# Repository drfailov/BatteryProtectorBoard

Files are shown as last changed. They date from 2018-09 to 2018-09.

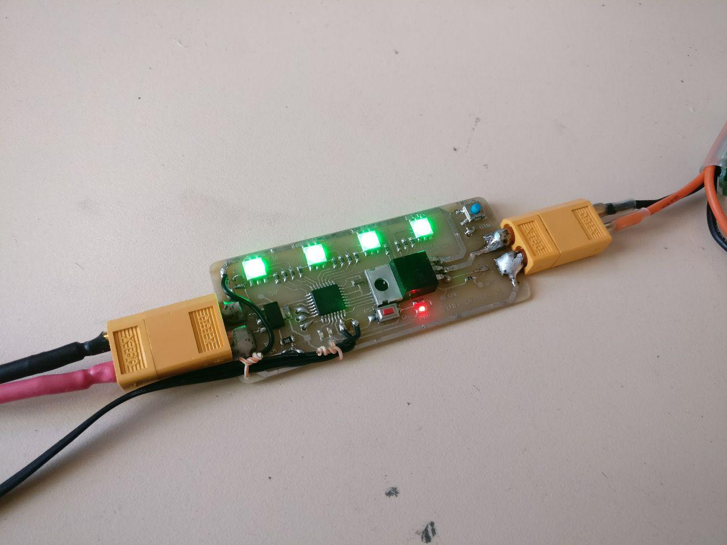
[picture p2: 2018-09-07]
Doc/2018-06-06 Board prototype.jpg

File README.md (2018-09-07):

# BatteryProtectorBoard
Этот проект описывает плату защиты акуумулятора и включает в себя: 
- Схему устройства
- Чертёж платы 
- Исходник платы в виде EasyEDA JSON
- Прошивку для Atmel 328p
- Схемы, чертежи, наброски
- Фото прототипа платы

Характеристики: 
- Рабочее напряжение: 5-15В
- Потребление тока в простое: 35мА
- Потребление тока минимум 20мА максимум 70 мА
- Рабочий ток для подключённого устройства: 1А
- Пиковый ток для подключённого устройства: 3А
- Точность измерения напряжения +-0.05В

Плата состоит из:
- Тестолитовая плата, 2 сторонняя
- Atmel 328p
- Диод 1n4007
- Кварцевый резонатор для Atmel
- Линейный стабилизатор напряжения AMS1117
- Силовой мосфет IRF520N
- 2 кнопки
- 4 RGB светодиода
- 2 разъёма XT-60
- 3 SMD светодиода
- 2 конденсатора 100мкФ 25В (для стабилизации напряжения)
- 1 SMD резистор на 180 Ом (маркировка 181) (для делителя напряжения)
- 1 SMD резистор на 2.2 кОм (маркировка 222) (для делителя напряжения)
- 15 SMD резисторов на 1 кОм (маркировка 102 или 1001)

Умеет делать:
- Измерять напряжение на входе
- Управлять питанием устройства на выхоже
- Отключать устройство при достижении нижнего порога напряжения
- Отключать устройство при достижении верхнего порога напряжения
- Отключать устройство с кнопки (если подержать секунду)
- Показывать уровень заряда 4мя светодиодами (с учётом нелинейности падения напряжения для литиевых аккумуляторов)
- Калиброваться в диапазоне напряжений 5В - 18В (по дефолту калиброван для 3S аккумулятора)
- Программироваться как Arduino, можно допиливать по своему усмотрению

Как изготавливать:
- Изготовить плату последней версии в папке с Gerber файлами.
- Распаять комплектуху. Atmel идеально снимать с Arduino Pro Mini, она уже прошита так как нужно.
- Открыть скетч в редакторе Arduino, скомпилировать.
- Прошить плату по UART через FTDI программатор. Во время прошивки ткнуть reset, чтобы началась прошивка.
- Проверить расниновку светодиодов на плате и соответствие цветов. Заряд более 40% должен отобраться зелёным, а калибровка синим.
(Если цвета не соответствуют, исправить константы описывающие распиновку диодов)
- Готово.

Как пользоваться:
После включения в течении секунды отображается анимация включения, после чего переход в режим отображеня заряда. 
В режиме отображения заряда заряд ниже 40% отображается розовым цветом, а заряд выше 40% отображается зелёным цветом.
При напряжении ниже минимального (стандартно это 10В) все светодиоды мигают розовым цветом, а подключённое устройство обесточивается.
При напряжении выше максимального (стандартно это 12.5В) все светодиоды мигают зелёным цветом, а подключённое устройство обесточивается.
Чтобы вручную отключить подключённое устройство, необходимо подержать кнопку 1 секунду, до завершения анимации, после чего 4й светодиод загорится синим. 
Это означает, что устройство обесточено вручную.В таком режиме плата будет находиться пока устройство не будет включено обратно вручную.  
Чтобы включить устройство обратно, требуется подержать кнопку нажатой секунду до завершения анимации, после чего плата переходит в режим отображения уровня заряда.

Как калибровать:
Диапазон напряжений можно калибровать. Он может находиться в диапазоне от 5В до 18В. 
Чтобы перейти в режим калибровки, нужно подключить плату к регулируемому блоку питания и перезагрузить плату держа нажатой кнопку выключения.
Когда режим калибровки активен, все светодиоды светят синим цветом. 
После того как Вы отпустите кнопку выключения, начнёт мигать зелёным 4й светодиод, это означает что сейчас калибруется верхний порог напряжения. 
Выставьте на блоке питания желаемое верхнее напряжение, убедитесь напряжение стабильно и нажмите кнопку включения на плате. 
В течении нескольких секунд плата будет измерять напряжение и сохранит измеренное напряжение в памяти и перейдёт в режим калибровки нижнего порога напряжения.
В режиме калибровки нижнего порога напряжения начнёт мигать 1й светодиод красным цветом. Выставьте на блоке питания желаемое нижнее напряжение и нажмите кнопку выключения. 
В течении нескольких секунд плата будет измерять напряжение и сохранит измеренное напряжение в памяти и перейдёт в режим отображения уровня заряда (нормальной работы).

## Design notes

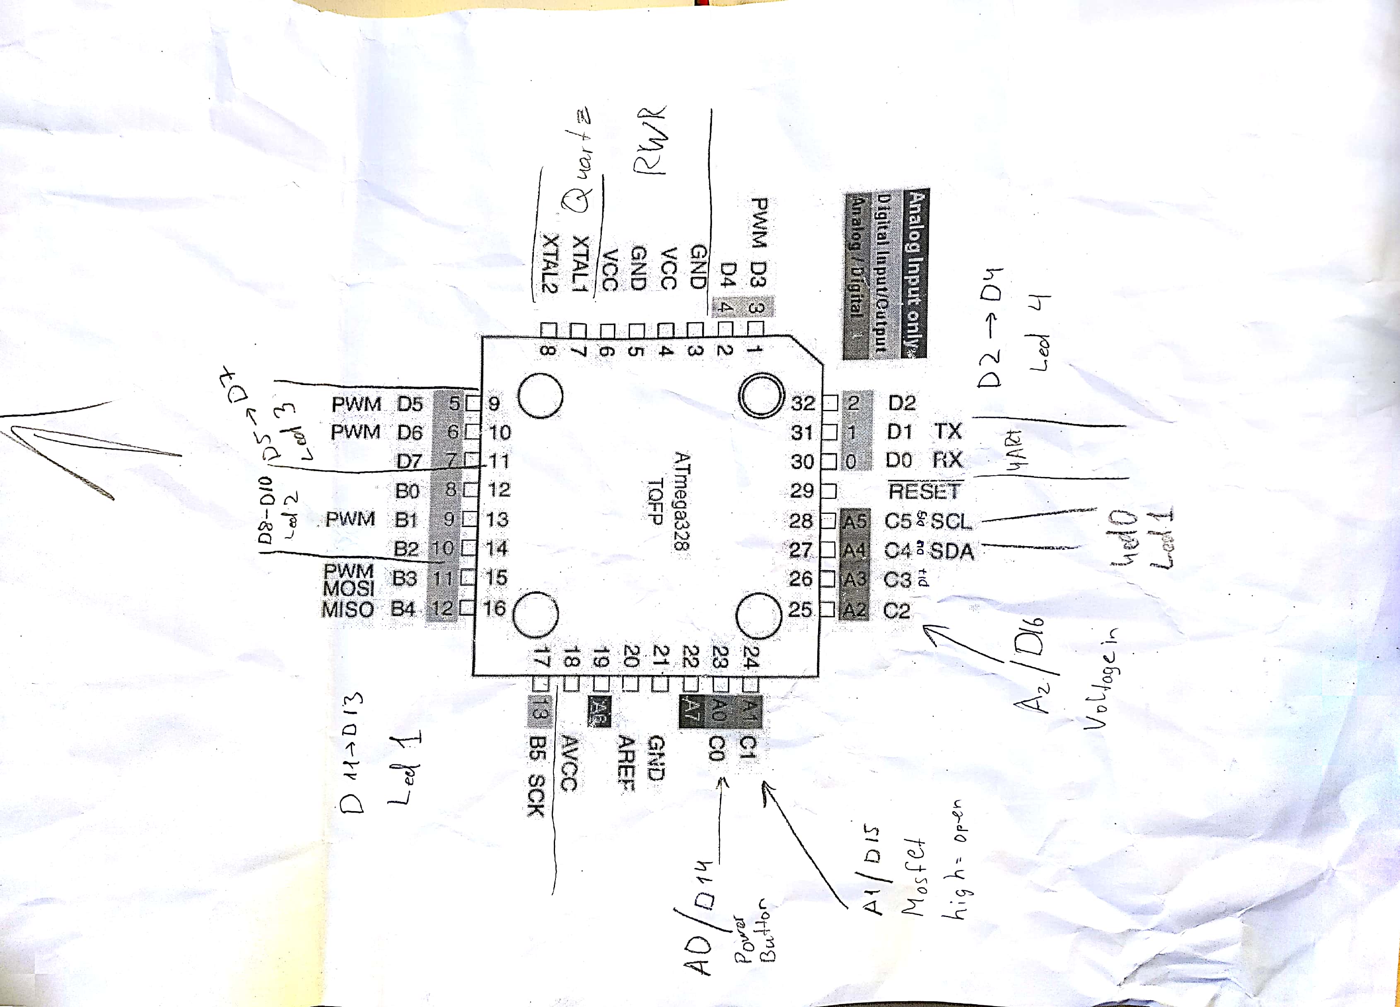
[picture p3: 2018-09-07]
Doc/2018-05-28 Atmel pinout.jpg

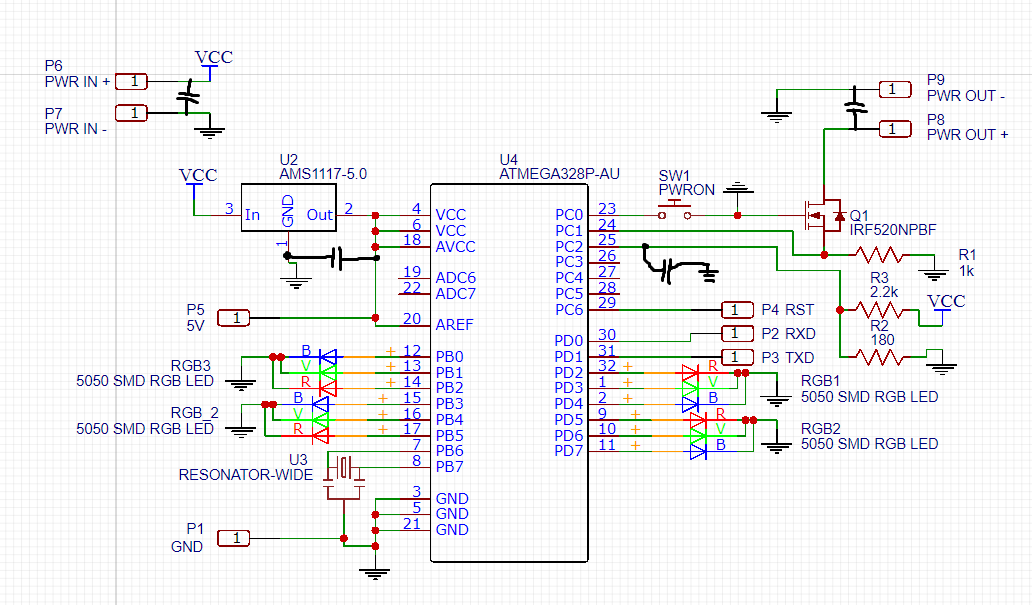
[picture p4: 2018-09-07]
Doc/2018-05-22 schematic.PNG

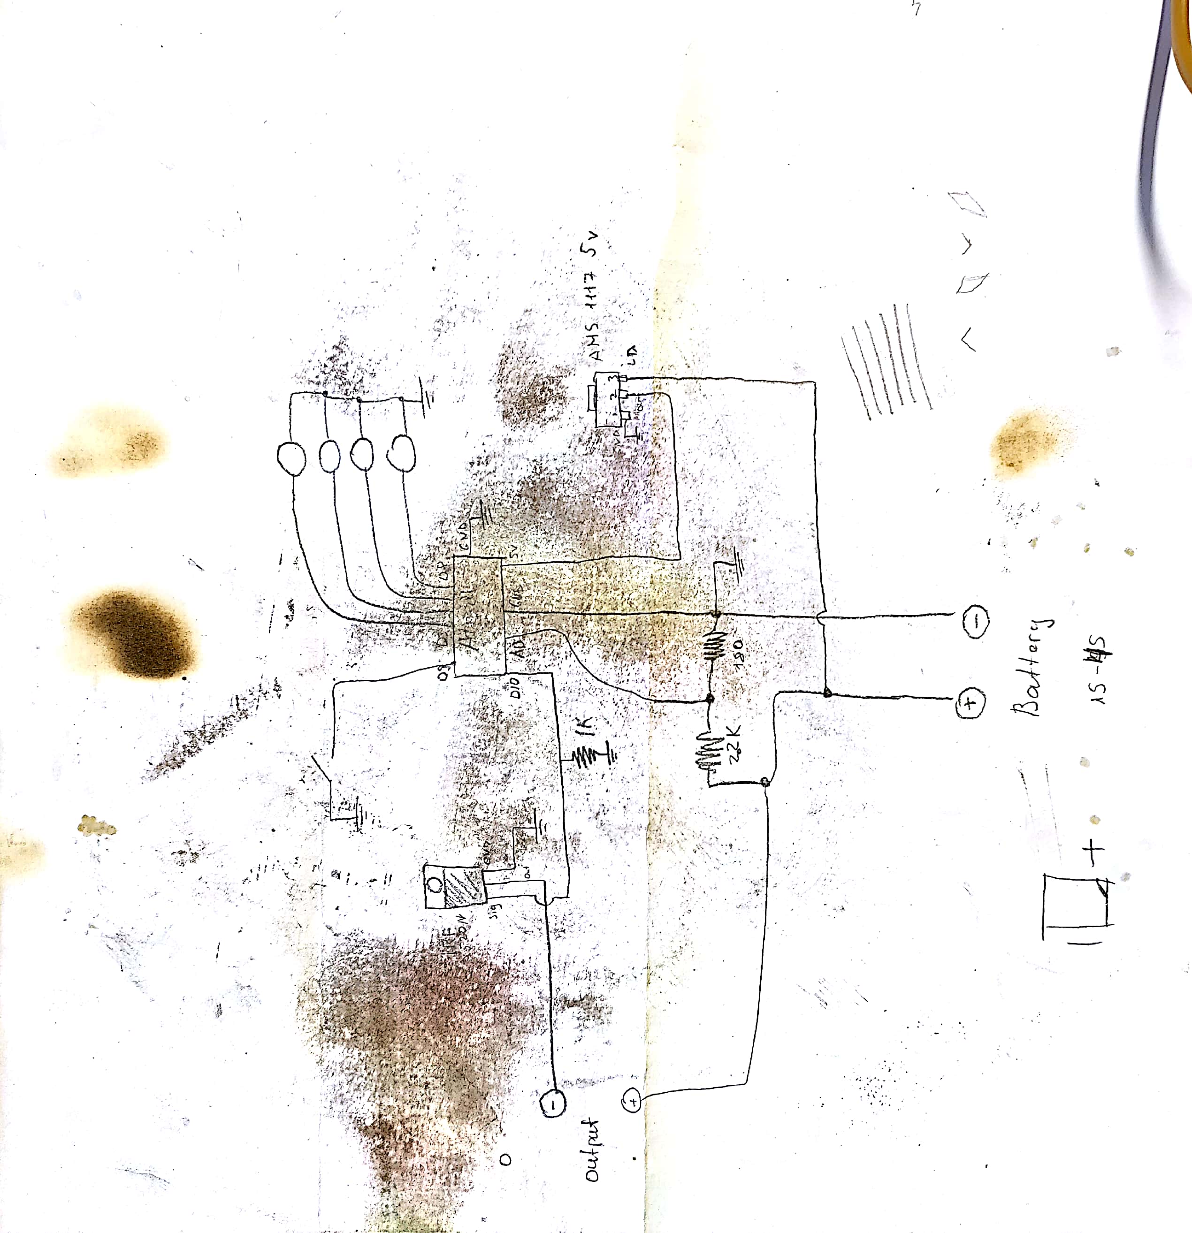
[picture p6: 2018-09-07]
Doc/2018-04-01 First investigations.jpg

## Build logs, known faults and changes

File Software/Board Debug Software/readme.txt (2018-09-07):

This program only sending positive signals to each port in order. And prints to log analog reads. Nothing more.

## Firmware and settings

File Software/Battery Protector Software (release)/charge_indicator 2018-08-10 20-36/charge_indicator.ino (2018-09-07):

int MODE_NORMAL = 0;
int MODE_ENABLING = 1;
int MODE_DISABLING = 2;
int MODE_DISABLED = 3;
int MODE_OVERVOLTAGE = 4;
int MODE_DISCHARGED = 5;
int MODE_CALIBRATION_HIGH = 6;
int MODE_CALIBRATION_LOW = 7;
int MODE_PRE_CALIBRATION = 8;
int MODE_SET_TIMER = 9;

int currentMode = MODE_NORMAL;




void setup() {
  Serial.begin(9600);
  Serial.println("Hello!:)");
  initLed();
  initButton();
  initVoltage();
  initMosfet();
  initTimer();  

  //Просто анимация
  for(int i=0; i<100; i++){
    ledPercent(i);
    delay(4);
  }
  //delay(50);


  if(isButtonPressed()){
    setPreCalibrationMode();
  }
  else{
    setNormalMode();
  }
}

void loop() {
  if(currentMode == MODE_NORMAL)
    modeNormalLoop();  
  else if(currentMode == MODE_ENABLING)
    modeEnablingLoop();  
  else if(currentMode == MODE_DISABLING)
    modeDisablingLoop();  
  else if(currentMode == MODE_DISABLED)
    modeDisabledLoop();  
  else if(currentMode == MODE_OVERVOLTAGE)
    modeOvervoltageLoop();  
  else if(currentMode == MODE_DISCHARGED)
    modeDischargedLoop();  
  else if(currentMode == MODE_CALIBRATION_HIGH)
    modeCalibrationHighLoop();  
  else if(currentMode == MODE_CALIBRATION_LOW)
    modeCalibrationLowLoop();  
  else if(currentMode == MODE_PRE_CALIBRATION)
    modePreCalibrationLoop();  
  else if(currentMode == MODE_SET_TIMER)
    modeSetTimerLoop();  
  delay(1);
}

void onButtonDown(){
  Serial.println("Button down");
  if(currentMode == MODE_NORMAL)
    modeNormalButtonDown();  
  else if(currentMode == MODE_ENABLING)
    modeEnablingButtonDown();  
  else if(currentMode == MODE_DISABLING)
    modeDisablingButtonDown();  
  else if(currentMode == MODE_DISABLED)
    modeDisabledButtonDown();  
  else if(currentMode == MODE_OVERVOLTAGE)
    modeOvervoltageButtonDown();  
  else if(currentMode == MODE_DISCHARGED)
    modeDischargedButtonDown();  
  else if(currentMode == MODE_CALIBRATION_HIGH)
    modeCalibrationHighButtonDown();  
  else if(currentMode == MODE_CALIBRATION_LOW)
    modeCalibrationLowButtonDown();  
  else if(currentMode == MODE_PRE_CALIBRATION)
    modePreCalibrationButtonDown(); 
  else if(currentMode == MODE_SET_TIMER)
    modeSetTimerButtonDown();  
}
void onButtonUp(){
  Serial.println("Button up");
  if(currentMode == MODE_NORMAL)
    modeNormalButtonUp();  
  else if(currentMode == MODE_ENABLING)
    modeEnablingButtonUp();  
  else if(currentMode == MODE_DISABLING)
    modeDisablingButtonUp();  
  else if(currentMode == MODE_DISABLED)
    modeDisabledButtonUp();  
  else if(currentMode == MODE_OVERVOLTAGE)
    modeOvervoltageButtonUp();  
  else if(currentMode == MODE_DISCHARGED)
    modeDischargedButtonUp();  
  else if(currentMode == MODE_CALIBRATION_HIGH)
    modeCalibrationHighButtonUp();  
  else if(currentMode == MODE_CALIBRATION_LOW)
    modeCalibrationLowButtonUp();  
  else if(currentMode == MODE_PRE_CALIBRATION)
    modePreCalibrationButtonUp();  
  else if(currentMode == MODE_SET_TIMER)
    modeSetTimerButtonUp();  
}

void setNormalMode(){
  Serial.println("Normal mode");
  currentMode = MODE_NORMAL;
  modeNormalSetup();
}

void setEnablingMode(){
  Serial.println("Enabling mode");
  currentMode = MODE_ENABLING;
  modeEnablingSetup();
}

void setDisablingMode(){
  Serial.println("Disabling mode");
  currentMode = MODE_DISABLING;
  modeDisablingSetup();
}

void setDisabledMode(){
  Serial.println("Disabled mode");
  currentMode = MODE_DISABLED;
  modeDisabledSetup();
}

void setOvervoltageMode(){
  Serial.println("Overvoltage mode");
  currentMode = MODE_OVERVOLTAGE;
  modeOvervoltageSetup();
}

void setDischargedMode(){
  Serial.println("Discharged mode");
  currentMode = MODE_DISCHARGED;
  modeDischargedSetup();
}

void setCalibrationHighMode(){
  Serial.println("Calibration high mode");
  currentMode = MODE_CALIBRATION_HIGH;
  modeCalibrationHighSetup();
}

void setCalibrationLowMode(){
  Serial.println("Calibration low mode");
  currentMode = MODE_CALIBRATION_LOW;
  modeCalibrationLowSetup();
}

void setPreCalibrationMode(){
  Serial.println("PRE Calibration mode");
  currentMode = MODE_PRE_CALIBRATION;
  modePreCalibrationSetup();
}

void setSetTimerMode(){
  Serial.println("Set Timer mode");
  currentMode = MODE_SET_TIMER;
  modeSetTimerSetup();
}

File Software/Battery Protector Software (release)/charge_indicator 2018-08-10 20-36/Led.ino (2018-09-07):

int RED = 0;
int BLUE = 1;
int GREEN = 2;
int CYAN = 3;
int MAGENTA = 4;
int YELLOW = 5;
int WHITE = 6;
int BLACK = 7;

int led1R_pin = 12;
int led1G_pin = 13;
int led1B_pin = 11;
int led2R_pin = 8;
int led2G_pin = 9;
int led2B_pin = 10;
int led3R_pin = 7;
int led3G_pin = 5;
int led3B_pin = 6;
int led4R_pin = 3;
int led4G_pin = 4;
int led4B_pin = 2;


//Этот блок нужен для того, чтобы реализовать мигание диодами.
//Нам достаточно задать два разных цвета для каждого диода и он будет мигать между ними
long lastTick = 0;
long blinkPeriod = 400;
int color = 1;//какой набор цветов сейчас
int led1_color1 = BLACK;
int led2_color1 = BLACK;
int led3_color1 = BLACK;
int led4_color1 = BLACK;
int led1_color2 = BLACK;
int led2_color2 = BLACK;
int led3_color2 = BLACK;
int led4_color2 = BLACK;


void initLed(){
  pinMode(led1R_pin, OUTPUT);
  pinMode(led1G_pin, OUTPUT);
  pinMode(led1B_pin, OUTPUT);
  pinMode(led2R_pin, OUTPUT);
  pinMode(led2G_pin, OUTPUT);
  pinMode(led2B_pin, OUTPUT);
  pinMode(led3R_pin, OUTPUT);
  pinMode(led3G_pin, OUTPUT);
  pinMode(led3B_pin, OUTPUT);
  pinMode(led4R_pin, OUTPUT);
  pinMode(led4G_pin, OUTPUT);
  pinMode(led4B_pin, OUTPUT);
}

void ledLoop(){
  if(millis() - lastTick > blinkPeriod){
    if(color == 1){
      led1(led1_color2);
      led2(led2_color2);
      led3(led3_color2);
      led4(led4_color2);
      color = 2;
    }
    else if(color == 2){
      led1(led1_color1);
      led2(led2_color1);
      led3(led3_color1);
      led4(led4_color1);
      color = 1;
    }
    lastTick = millis();
  }
}

void ledWaitFor(int sec, int color){
  long started = millis();
  int ledn = 1;
  while(millis() - started < sec * 1000){
    if(ledn == 1)
      led(color, BLACK, BLACK, BLACK);
    if(ledn == 2)
      led(BLACK, color, BLACK, BLACK);
    if(ledn == 3)
      led(BLACK, BLACK, color, BLACK);
    if(ledn == 4)
      led(BLACK, BLACK, BLACK, color);
    
    delay(100);
    ledn ++;
    if(ledn > 4)
      ledn = 1;
  }
}

void ledPercent(int percent){
  int FIRST = RED;
  int SECOND = YELLOW;
  while(percent > 100)
    percent -= 100;
  if(percent > 96) led(SECOND, SECOND, SECOND, SECOND);
  else if(percent > 84) led(SECOND, SECOND, SECOND, FIRST);
  else if(percent > 72) led(SECOND, SECOND, FIRST, FIRST);
  else if(percent > 60) led(SECOND, FIRST, FIRST, FIRST);
  else if(percent > 48) led(FIRST, FIRST, FIRST, FIRST);
  else if(percent > 36) led(FIRST, FIRST, FIRST, BLACK);
  else if(percent > 24) led(FIRST, FIRST, BLACK, BLACK);
  else if(percent > 12) led(FIRST, BLACK, BLACK, BLACK);
  else if(percent > 0) led(BLACK, BLACK, BLACK, BLACK);
}


void ledPercentOld(int percent){
  while(percent > 200)
    percent -= 200;
  if(percent > 200) led(GREEN, BLACK, BLACK, BLACK);
  else if(percent > 188) led(BLACK, BLACK, BLACK, BLACK);
  else if(percent > 180) led(BLACK, BLACK, BLACK, BLUE);
  else if(percent > 172) led(BLACK, BLACK, BLACK, YELLOW);
  else if(percent > 164) led(BLACK, BLACK, BLACK, WHITE);
  else if(percent > 156) led(BLACK, BLACK, BLUE, WHITE);
  else if(percent > 148) led(BLACK, BLACK, YELLOW, WHITE);
  else if(percent > 140) led(BLACK, BLACK, WHITE, WHITE);
  else if(percent > 132) led(BLACK, BLUE, WHITE, WHITE);
  else if(percent > 124) led(BLACK, YELLOW, WHITE, WHITE);
  else if(percent > 116) led(BLACK, WHITE, WHITE, WHITE);
  else if(percent > 108) led(BLUE, WHITE, WHITE, WHITE);
  else if(percent > 100) led(YELLOW, WHITE, WHITE, WHITE);
  else if(percent > 96) led(WHITE, WHITE, WHITE, WHITE);
  else if(percent > 88) led(WHITE, WHITE, WHITE, YELLOW);
  else if(percent > 80) led(WHITE, WHITE, WHITE, RED);
  else if(percent > 72) led(WHITE, WHITE, WHITE, BLACK);
  else if(percent > 64) led(WHITE, WHITE, YELLOW, BLACK);
  else if(percent > 56) led(WHITE, WHITE, RED, BLACK);
  else if(percent > 48) led(WHITE, WHITE, BLACK, BLACK);
  else if(percent > 40) led(WHITE, YELLOW, BLACK, BLACK);
  else if(percent > 32) led(WHITE, RED, BLACK, BLACK);
  else if(percent > 24) led(WHITE, BLACK, BLACK, BLACK);
  else if(percent > 16) led(YELLOW, BLACK, BLACK, BLACK);
  else if(percent > 8) led(RED, BLACK, BLACK, BLACK);
  else if(percent > 0) led(BLACK, BLACK, BLACK, BLACK);
}

void led(int l1c1, int l1c2, int l2c1, int l2c2, int l3c1, int l3c2, int l4c1, int l4c2){
  led1_color1 = l1c1;
  led2_color1 = l2c1;
  led3_color1 = l3c1;
  led4_color1 = l4c1;
  led1_color2 = l1c2;
  led2_color2 = l2c2;
  led3_color2 = l3c2;
  led4_color2 = l4c2;
}

void led(int c1, int c2, int c3, int c4){
  led1_color1 = c1;
  led2_color1 = c2;
  led3_color1 = c3;
  led4_color1 = c4;
  led1_color2 = c1;
  led2_color2 = c2;
  led3_color2 = c3;
  led4_color2 = c4;
  led1(c1);
  led2(c2);
  led3(c3);
  led4(c4);
}
void led1(int color){
  digitalWrite(led1R_pin, (color == RED || color == YELLOW || color == MAGENTA || color == WHITE?HIGH:LOW));
  digitalWrite(led1G_pin, (color == GREEN || color == YELLOW || color == CYAN || color == WHITE?HIGH:LOW));
  digitalWrite(led1B_pin, (color == BLUE || color == CYAN || color == MAGENTA || color == WHITE?HIGH:LOW));
}
void led2(int color){
  digitalWrite(led2R_pin, (color == RED || color == YELLOW || color == MAGENTA || color == WHITE?HIGH:LOW));
  digitalWrite(led2G_pin, (color == GREEN || color == YELLOW || color == CYAN || color == WHITE?HIGH:LOW));
  digitalWrite(led2B_pin, (color == BLUE || color == CYAN || color == MAGENTA || color == WHITE?HIGH:LOW));
}
void led3(int color){
  digitalWrite(led3R_pin, (color == RED || color == YELLOW || color == MAGENTA || color == WHITE?HIGH:LOW));
  digitalWrite(led3G_pin, (color == GREEN || color == YELLOW || color == CYAN || color == WHITE?HIGH:LOW));
  digitalWrite(led3B_pin, (color == BLUE || color == CYAN || color == MAGENTA || color == WHITE?HIGH:LOW));
}
void led4(int color){
  digitalWrite(led4R_pin, (color == RED || color == YELLOW || color == MAGENTA || color == WHITE?HIGH:LOW));
  digitalWrite(led4G_pin, (color == GREEN || color == YELLOW || color == CYAN || color == WHITE?HIGH:LOW));
  digitalWrite(led4B_pin, (color == BLUE || color == CYAN || color == MAGENTA || color == WHITE?HIGH:LOW));
}
